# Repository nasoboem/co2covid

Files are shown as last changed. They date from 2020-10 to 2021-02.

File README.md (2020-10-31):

# Monitoring Covid 19 Aerosol through CO2 Concentration

## Hardware:
    
- ESP32
- MH-Z19 CO2 sensor
- 6x 10mm LEDs
- 6x 68 Ohm resistors
- PCB or perfboard

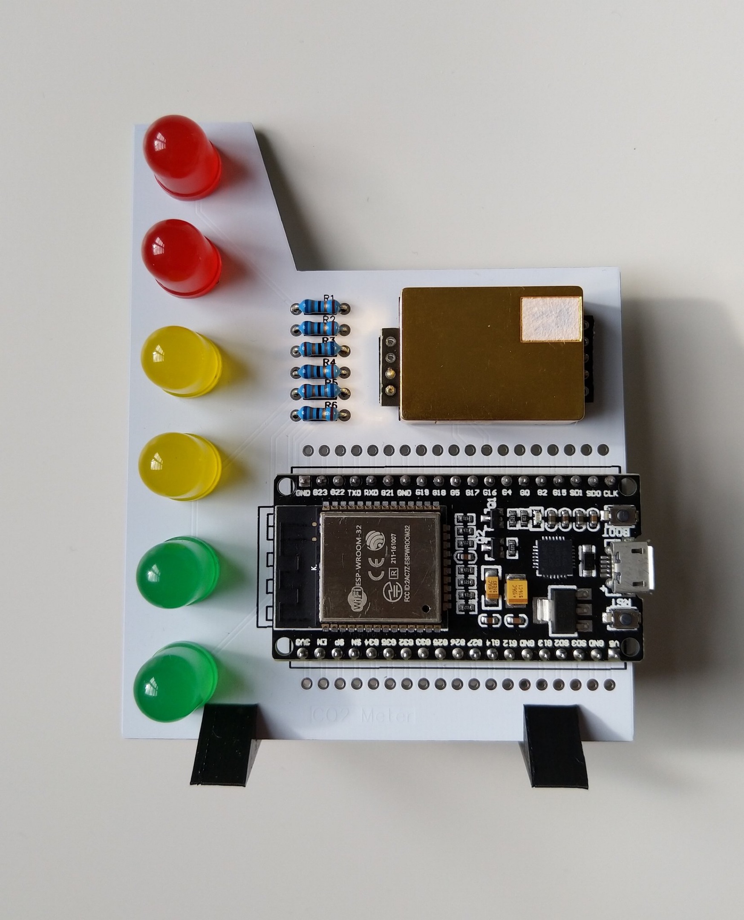
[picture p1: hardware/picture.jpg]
assembled PCB


## Code

####    onlyled

- show the CO2 level on the six leds

## Schematic

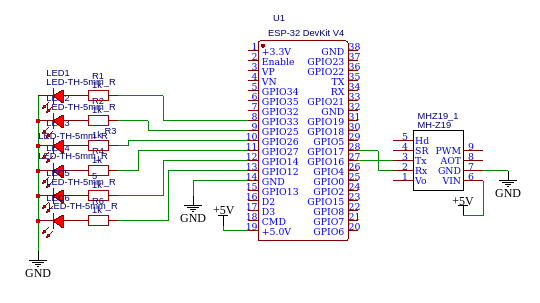
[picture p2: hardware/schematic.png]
Schematic


## PCB

look at my EasyEDA project:
https://easyeda.com/koning.unauwen/co2measure_copy

## flashing firmware to ESP32

- download Arduino IDE
- install ESP32 core
- upload program

## TODO

- data to database (influxdb) via WiFi
- display data with grafana

## contribute

If something is wrong, not clear, doesn't work or could be designed better, feel free to create an issue.

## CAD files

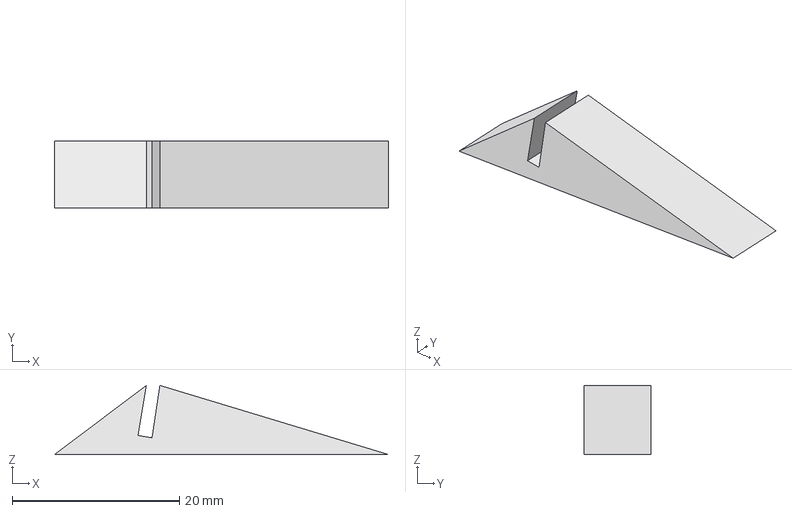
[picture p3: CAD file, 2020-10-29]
hardware/pcbbase.FCStd
40.0 x 8.00 x 8.28 mm

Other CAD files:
hardware/pcbbase.stl

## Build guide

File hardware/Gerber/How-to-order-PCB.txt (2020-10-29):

How to Order PCB

Please refer to:
https://docs.easyeda.com/en/PCB/Order-PCB

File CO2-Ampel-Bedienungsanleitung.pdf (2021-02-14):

# CO2-Ampel

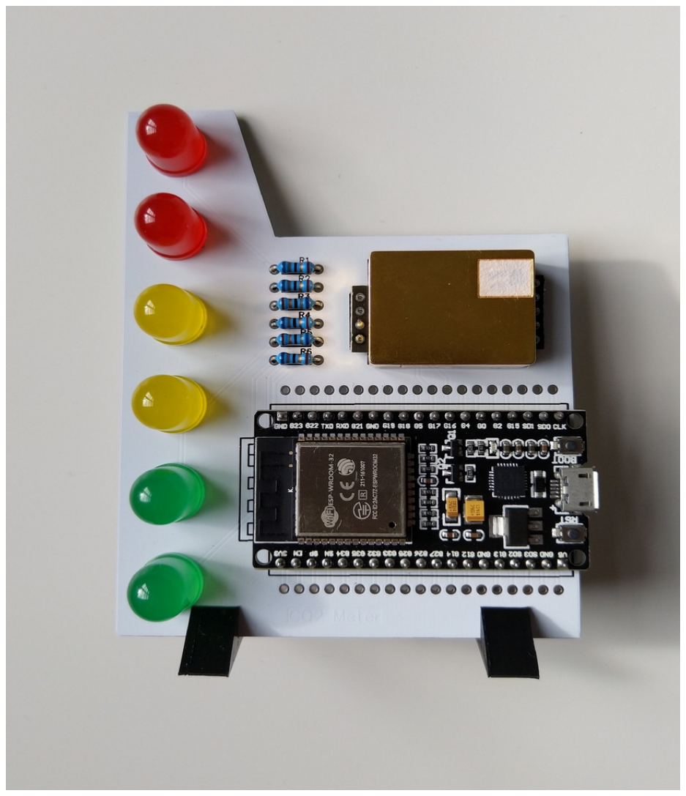
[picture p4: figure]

### Forscher-AG Werner-von-Siemens-Gymnasium Berlin

### Bei fragen: haettig@siemens-gymnasium-berlin.de naso@explain-it-arium.de

### Dokumentation, Software und Teileliste: https://github.com/nasoboem/co2covid (https://github.com/brouwerb/co2covid)

### Aufbau:

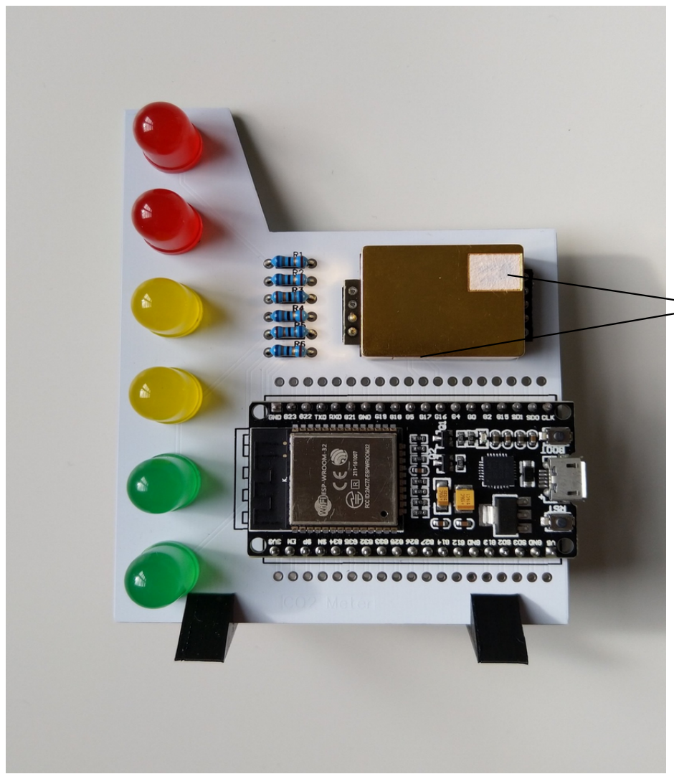
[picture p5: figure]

### Das Video, das die Funktionen der CO2-Ampel zeigt, finden sie hier:

### https://youtu.be/PujqlDoSrls

Inbetriebnahme:

Da der Sensor sich nach einer 1 min (älterer Sensor MH-Z19B 3 min) Aufwärmphase (Blinklauf nach oben) auf 400ppm kalibriert ist es wichtig, dass der Sensor in einem gut gelüfteten Raum in betrieb genommen wird. Der Hersteller empfiehlt für eine sichere Kalibrierung 20 min, es hat sich aber gezeigt, dass es auch mit deutlich kürzeren Zeiten geht. 3 min Stoßlüften, dann kann das Gerät eingesteckt werden. Wenn der Blinklauf beendet ist und ein bis zwei LED angezeigt werden können die Fenster wieder geschlossen werden.

Der Sensor verfügt über eine Autokalibrierung, die den niedrigsten Wert in den letzten 24h auf 400ppm setzt. Auch wenn die Inbetriebnahme nicht optimal war, sollte der Sensor im laufe von 24h die richtigen Werte anzeigen.

Verwendung:

Die CO2-Ampel ist nicht wasserfest und sollte an einem trockenen, sicheren Standort aufgestellt werden. Die Ampel zeigt an wann gelüftet werden soll (Stoßlüften – Fenster und Türen ganz auf), nicht wie lange. Der Sensor ist etwas träge, wegen dem langsamen Gasaustausch und auch wegen dem langen Messzyklen (nur alle 15s). Gelüftet werden sollte, wenn die erste rote LED leuchtet. Gekippte Fenster reduzieren besser den CO2-Gehalt als den Aerosolgehalt in der Luft. Daher sollten gekippte Fenster vermieden werden. Die Werte fürs Lüften sind eine Empfehlung aus einem Paper von Hartmann & Kriegel – Risk assessment of aerosols loaded with virus based on CO2-concentartion – https://depositonce.tu-berlin.de/bitstream/11303/11478.3/9/hartmann_kriegel_2020_en_v3.pdf
Bitte passen sie Ihr Lüftverhalten den Gegebenheiten und neueren Erkenntnissen an. Die Ampel kann auch falsche Werte anzeigen.

Manuelle Kalibrierung:

Lange den Boot-Knopf drücken startet den Kalibriervorgang. Alle LEDs blinken für 3 min und dann wird die Kalibrierung durchgeführt. Bitte in den 3 min Stoßlüften (alle Fenster und Türen aufreißen).

### <600ppm

### >800ppm

### >900ppm

### >1100ppm

### >600ppm

### Fenster des Sensors

(Bauweise kann abweichen.)

### Nicht abdecken!!

### >1000ppm Lüften!!

Fehlerbehebung:

Sollte die CO2-Ampel sich seltsam verhalten, dann bitte den Netzstecker ziehen (nicht an der Ampel, sondern an der Steckdose – die Micro-USB-Buchse kann leicht abbrechen, wenn man sie häufiger mechanischen Belastungen aussetzt) und eine Inbetriebnahme durchführen. Sollten sich Probleme ergeben, die sich so nicht beheben lassen, kontaktieren Sie uns (haettig@siemens-gymnasium-berlin.de oder naso@explain-it-arium.de).

Zusammenbau des Bausatzes:

Das Video, das den Zusammenbau des Bausatzes beschreibt findet sich hier:

https://youtu.be/21HiPMb0zwE

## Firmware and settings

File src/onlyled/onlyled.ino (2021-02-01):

#include <Arduino.h>

#define RXD2 16 // connect to TXD on MH-19
#define TXD2 17 // connect ro RXD on MH-19



long lastMsg = 0;
char msg[50];
int value = 0;
unsigned long tim = 0;
bool pressed = false;

byte cmd[9] = {0xFF, 0x01, 0x86, 0x00, 0x00, 0x00, 0x00, 0x00, 0x79};  // get gas command
byte cmdCal[9] = {0xFF, 0x01, 0x87, 0x00, 0x00, 0x00, 0x00, 0x00, 0x78};  // calibrate command
byte autoCal[9] = {0xFF, 0x01, 0x79, 0xA0, 0x00, 0x00, 0x00, 0x00, 0xE6};  // enable autocalibration
char response[9];  // holds the recieved data

int CO2ppm = 0;

unsigned long warmingTimer = 0;
unsigned long previousMillis = 0;

int ledPins[] = {12, 14, 27, 26, 25, 33};
int si = sizeof(ledPins);

void setup()
{
  for (int index = 0; index < si; index++)
    {
        pinMode(ledPins[index], OUTPUT);
        digitalWrite(ledPins[index], HIGH);
    }
	
  Serial2.begin(9600, SERIAL_8N1, RXD2, TXD2); // Setup a serial connection with the sensor
  Serial.begin(115200);
	
  
  Serial2.write(autoCal,9); // activate to enable autocalibration
  
	 warmingTimer = millis();  // initilize warmup timer
   while (millis() - warmingTimer < 60000) // wait for one minutes - preheat time
	 {
         ledscroll();
	 }
	calibrate(); // activate to calibrate at startup
  pinMode(0, INPUT);
  

  
}

void loop()
{
  //reconnect();
  unsigned long currentMillis = millis();
	if ((unsigned long)(currentMillis - previousMillis) > 15000) {  // runs every 15 sec
	{
		getReadings();
		previousMillis = currentMillis;
	}
  }

  // check boot button to calibrate
  if (digitalRead(0) == 0 && pressed == false)
  {
    tim = millis();
    pressed = true;
  }
  else if (digitalRead(0) == 1)
  {
    pressed = false;
  }
  
  if (currentMillis - tim > 5000 && pressed == true)
  {
    calibrate();
    blink(3); // blink for 3 minutes
  }
  

} // loop

void getReadings()
{
	while (Serial2.available())  //clears recieve buffer
	{
		int garbage = Serial2.read();
	}

	Serial2.write(cmd, 9);  // read sensor
	Serial2.flush(); 

	while (!Serial2.available())  // wait for sensor response
	{
		delay(0);
	}

	Serial2.readBytes(response, 9);  // read responce once available
	int responseHigh = (int)response[2];
	int responseLow = (int)response[3];
	CO2ppm = (256 * responseHigh) + responseLow;
  // CO2ppm = analogRead(34); // dummy input to test without sensor
  String CO2String = String(CO2ppm);
  Serial.print("CO2: ");
	Serial.println(CO2String);
  char message_buff[8];
  CO2String.toCharArray(message_buff, CO2String.length()+1); 
    
  led(CO2ppm);
}

void calibrate()
{
	Serial2.write(cmdCal, 9);
	delay(3000);
}

// translate CO2 level to LEDs
void led(int CO2) {

    int lednum = 0;

    if(CO2 > 1100){lednum = 6;}
    else if(CO2 > 1000){lednum = 5;}
    else if(CO2 > 900){lednum = 4;}
    else if(CO2 > 800){lednum = 3;}
    else if(CO2 > 600){lednum = 2;}
    else{lednum = 1;}
    Serial.println(lednum);

    for (int index = 0; index < lednum; index++)
    {
      digitalWrite(ledPins[index], HIGH);
    }

    for (int index = lednum; index < si; index++)
    {
      digitalWrite(ledPins[index], LOW);
    }
  }

// animation for warmup
void ledscroll(){
   for (int index = 0; index <= si; index++)
  {
    if (index < si){
      digitalWrite(ledPins[index], HIGH);
    }
    if (index > 0) {
      digitalWrite(ledPins[index-1], LOW);
    }
    delay(100);
  }
}

void blink(int a)
{
  for (int i = 0; i < a*60; i++)
  {
    for (int index = 0; index < si; index++)
    {
      digitalWrite(ledPins[index], HIGH);
    }
    delay(500);
    for (int index = 0; index < si; index++)
    {
      digitalWrite(ledPins[index], LOW);
    }
    delay(500);
  }
  
}

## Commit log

2020-10-28 add schematic
2020-10-28 add gerber
    [Gerber_BoardOutline.GKO, Gerber_BottomLayer.GBL, Gerber_BottomSolderMaskLayer.GBS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]
2020-10-29 add pcb base
    [pcbbase.FCStd, pcbbase.stl]
2020-10-29 edit readme and gerber
    [Gerber_BoardOutline.GKO, Gerber_BottomLayer.GBL, Gerber_BottomSolderMaskLayer.GBS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]
2020-10-31 add calibration via boot button
2021-02-01 Update onlyled.ino
    - calibration via boot button shorten to 3 min (was 20 min)
    - enabled auto-calibration
    - enabled calibration on start
    [onlyled.ino]
2021-02-01 Update onlyled.ino
    - shorten preheat time to the recommended 1 min for the new MH-Z19C - https://www.winsen-sensor.com/sensors/co2-sensor/mh-z19c.html
    [onlyled.ino]
2021-02-01 Update and rename onlyled.ino to CO2-LED-Idicator-MH-Z19C.ino
    - Specifying the Sensor in the code
2021-02-14 CO2-LED-Indicator - Senseair-s8.ino
    That is the file if you want to use our PCB but with the Senseair-s8 CO2-Sensor
2021-02-14 Update CO2-LED-Indicator-Senseair-s8.ino
    This is the Code for the Senseair s8.
